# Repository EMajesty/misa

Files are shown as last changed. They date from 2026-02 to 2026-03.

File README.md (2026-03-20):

<p align="center">
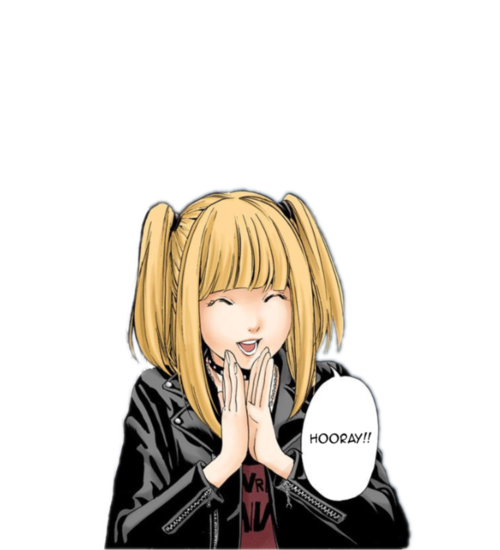
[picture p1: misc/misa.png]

</p>
<h1 align="center">MISA</h1>

<p align="center">
68k SBC somewhat inspired by the Lisa and the Mac, and similar projects around the net.
</p>

<p align="center">
MC68HC000P16 (at 4/8/16 MHz)
<br />
1MB ROM (2x SST39SF040)
<br />
1MB SRAM (2x AS6C4008-55PCN)
<br />
ATF1508 CPLD for glue
<br />
UART
<br />
CF card
<br />
Monochrome display
<br />
Audio with YM2151?
<br />
Keyboard?
<br />
Wifi with WizFi360???
</p>

<p align="center">
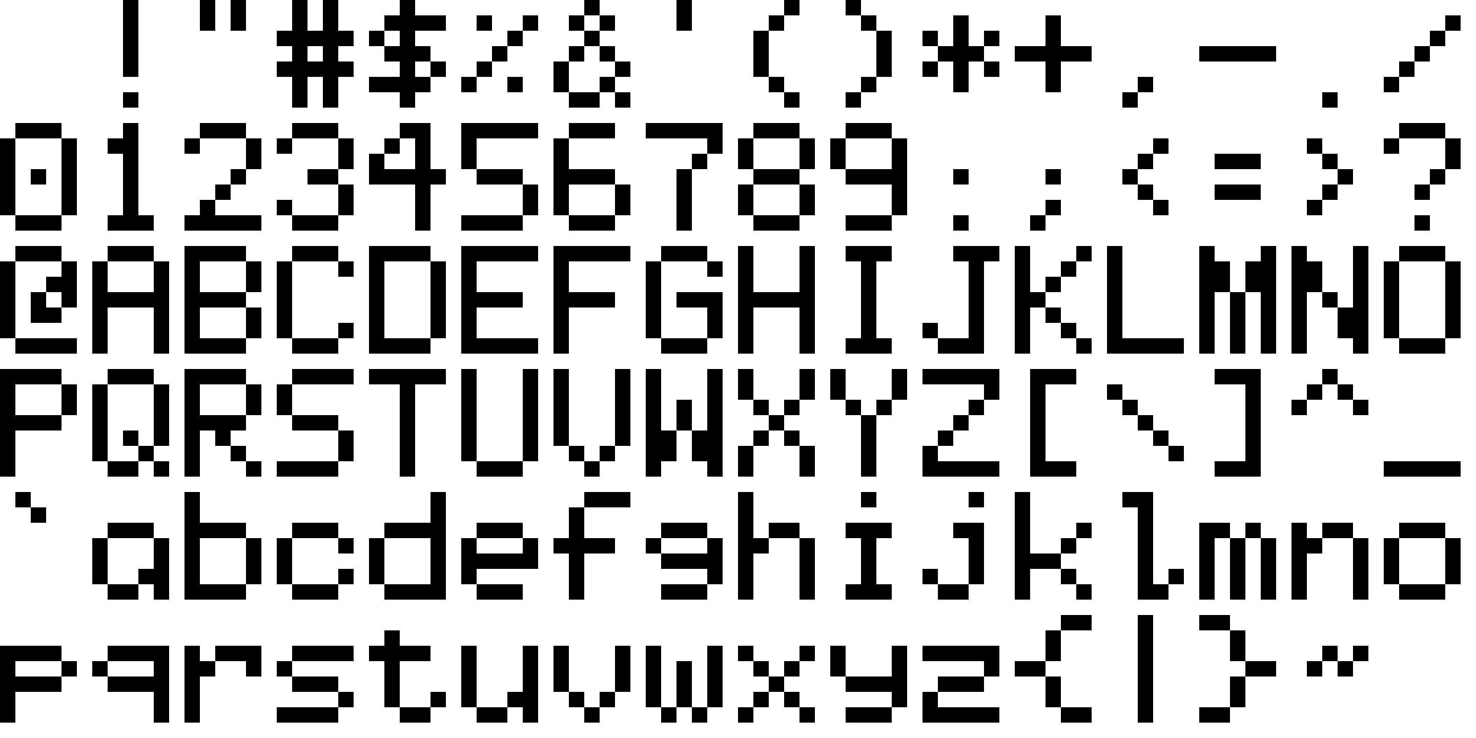
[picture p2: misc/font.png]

</p>

<p align="center">
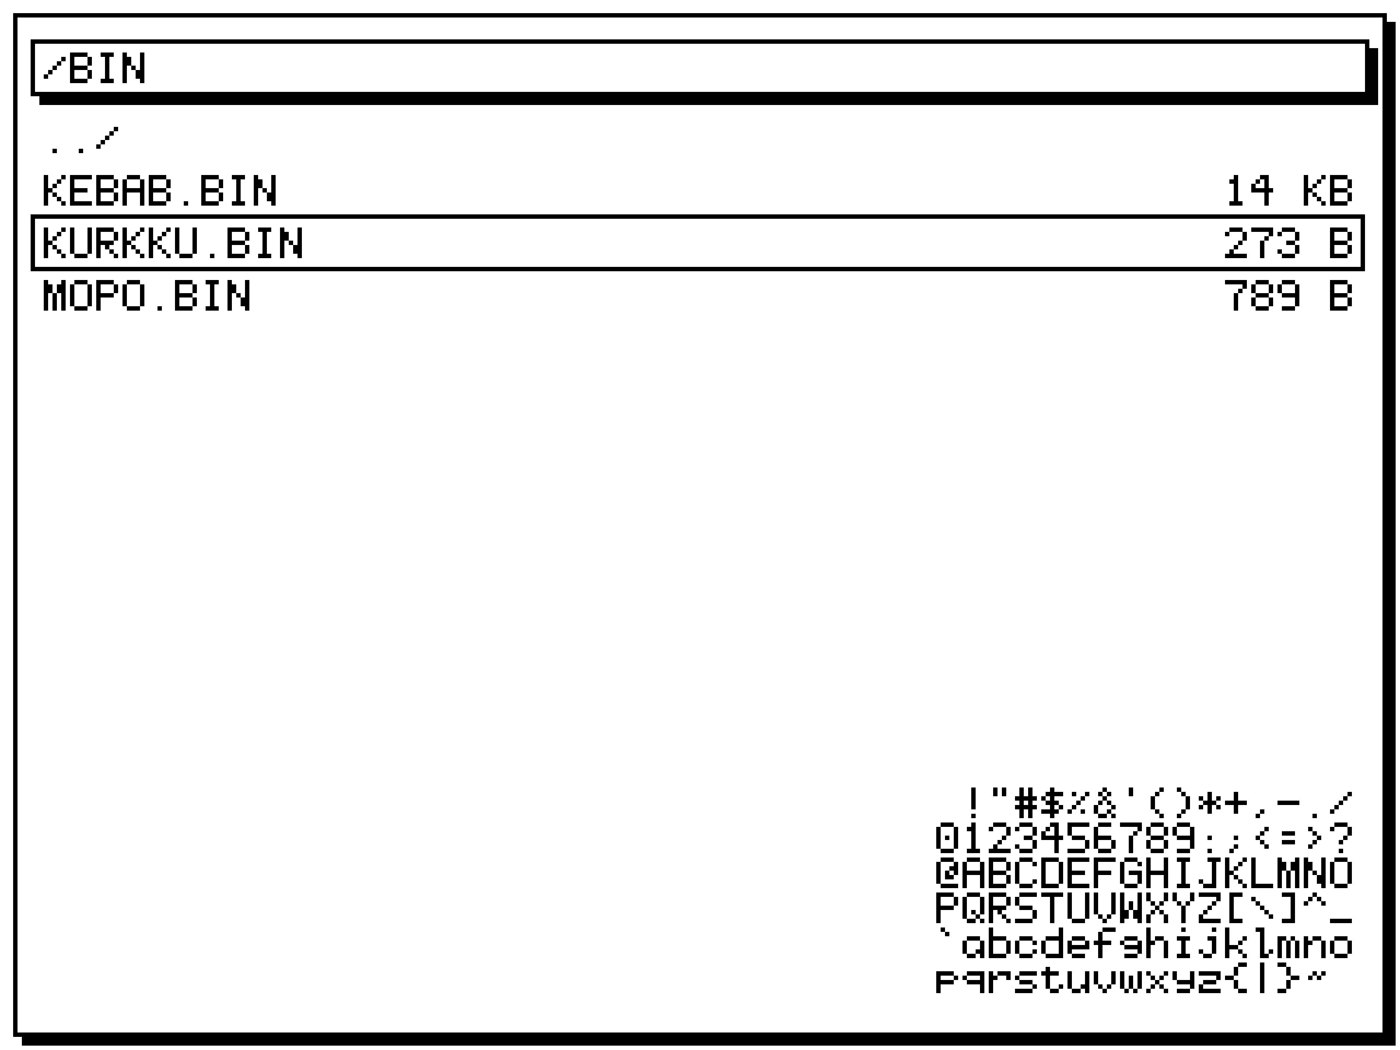
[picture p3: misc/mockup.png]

</p>

### TODO

- [ ] HW proto
- [ ] PLD logic
- [ ] Monitor program
- [ ] UART stuff
- [ ] Display stuff
- [x] Font 
- [ ] Input stuff
- [ ] FAT16/VFAT 
- [ ] File manager
- [ ] A beep
- [ ] Text editor
- [ ] Terminal emulator
- [ ] Lisp interpreter
- [ ] Doom
- [ ] ?????
- [ ] Multitasking kernel

### Docs

[68000 Hardware Manual](https://bitsavers.org/pdf/peripheralTechnology/68000_Hardware_Manual.pdf)

[M68000 User's Manual](https://www.nxp.com/docs/en/reference-manual/MC68000UM.pdf)

### BOM

| Ref | Part | Qty | Package | Datasheet | Notes |
|---|---|---|---|---|---|
||MC68HC000|1|DIP64/PLCC68|[Datasheet](https://igspgm.com/repairs/MC68HC000.pdf)|MPU|
||YM2151|1|DIP24|[Datasheet](https://retrocdn.net/images/1/1c/YM2151_datasheet.pdf)<br/>[Application manual](https://retrocdn.net/images/9/9c/YM2151_Application_Manual.pdf)|Sound|
||YM3012|1|DIP16|[Datasheet](https://datasheet4u.com/pdf-down/Y/M/3/YM3012-Yamaha.pdf)|DAC|
||TDA2822M|1|DIP8|[Datasheet](https://www.mouser.com/catalog/specsheets/stmicroelectronics_cd00000134.pdf)|Power amp|
||AS6C4008-55PCN|2|DIP32|[Datasheet](https://eu.mouser.com/datasheet/3/893/1/AS6C4008.pdf)|SRAM|
||SST39SF040|2|PLCC32|[Datasheet](https://ww1.microchip.com/downloads/aemDocuments/documents/MPD/ProductDocuments/DataSheets/SST39SF010A-SST39SF020A-SST39SF040-Data-Sheet-DS20005022.pdf)|ROM|
||ATF1508AS|1|PLCC84|[Datasheet](https://ww1.microchip.com/downloads/en/DeviceDoc/doc0784.pdf)|CPLD|
||MC68681FN|1|PLCC44|[Datasheet](https://www.microelectronicash.com/downloads/MC68681P.pdf)<br/>[AN-0899](https://www.bitsavers.org/components/motorola/_appNotes/AN-0899_A_Terminal_Interface,_Printer...for_an_MC68000-Based_System_using_the_MC68681_DUART.pdf)|DUART|
||NE555P|1|DIP8|[Datasheet](https://www.ti.com/lit/ds/symlink/se555.pdf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)||
||SN74HC05N|1|DIP14|[Datasheet](https://www.ti.com/lit/ds/symlink/sn74hc05.pdf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)||
||SN74HCT74N|1|DIP14|[Datasheet](https://www.ti.com/lit/ds/symlink/sn74hct74.pdf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)||
||16 MHz oscillator|1|DIP8|[Datasheet](https://www.ctscorp.com/Files/DataSheets/Passives/FCP/Clock-Oscillators/clock-ocillators-MXO45_MXO45HS-datasheet.pdf)||
||3.6864 MHz oscillator|1|DIP8|[Datasheet](https://www.ctscorp.com/Files/DataSheets/Passives/FCP/Clock-Oscillators/clock-ocillators-MXO45_MXO45HS-datasheet.pdf)||
||WizFi360-CON|1||[Datasheet](https://docs.wiznet.io/pdf-viewer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)|WIFI|
||5.7" 320240 RA8835|1||[Module](https://www.buydisplay.com/download/manual/ERM320240-1_Series_Datasheet.pdf)<br />[Controller](https://www.buydisplay.com/download/ic/RA8835.pdf)|Display|

### Memory map (RAM vectors + 2 MiB I/O)

| Region | Start | End | Size | Notes |
|---|---|---|---|---|
| ROM | 0x00000000 | 0x000FFFFF | 1 MiB  | 2x SST39SF040; contains reset vectors, monitor, bootloader; early startup runs from here. |
| Vectors | 0x00100000 | 0x001003FF | 1 KiB  | Vector table copied from ROM into RAM at boot; CPU configured to use RAM vectors.|
| RAM | 0x00100000 | 0x001FFFFF | 1 MiB  | Same 1 MiB SRAM; low area holds vectors + kernel data, high end used for supervisor/user stacks and heap. |
| I/O | 0x00E00000 | 0x00FFFFFF | 2 MiB  | CPLD‑decoded I/O window for UART, IDE/CF, keyboard, video, audio, WiFi, unused space.|
| Unused  | Everything else | - | - ||

### I/O submap (0x00E00000–0x00FFFFFF)

| Device | CS | Start | End | Size | Bus width | Notes |
|---|---|---|---|---|---|---|
| UART | UART_CS | 0x00E00000 | 0x00E00FFF | 4 KiB | 8‑bit | MC68681FN on D0–D7, RS0–RS3 from CPU A1–A4.|
| IDE / CF| IDE_CS0/1 | 0x00E01000 | 0x00E01FFF | 4 KiB | 16‑bit | 16‑bit data path via CPLD, command/control regs.|
| Keyboard| KBD_CS | 0x00E02000 | 0x00E02FFF | 4 KiB | 8‑bit | Simple DATA/STATUS/CONTROL registers.|
| Video | VID_CS | 0x00E03000 | 0x00E03FFF | 4 KiB | 8‑ or 16‑bit | RA8835 controller regs; framebuffer mapped elsewhere or via paging.|
| Audio | AUD_CS | 0x00E04000 | 0x00E04FFF | 4 KiB | 8‑bit | YM2151 register interface; DAC/analog path is fixed hardware, no CPU control.|
| WiFi | WIFI_CS | 0x00E05000 | 0x00E05FFF | 4 KiB | 8‑bit | WizFi360 memory‑mapped UART/command regs (future). |
| Unused  | – | 0x00E06000 | 0x00FFFFFF | ~1.97 MiB | 8‑ or 16‑bit ||

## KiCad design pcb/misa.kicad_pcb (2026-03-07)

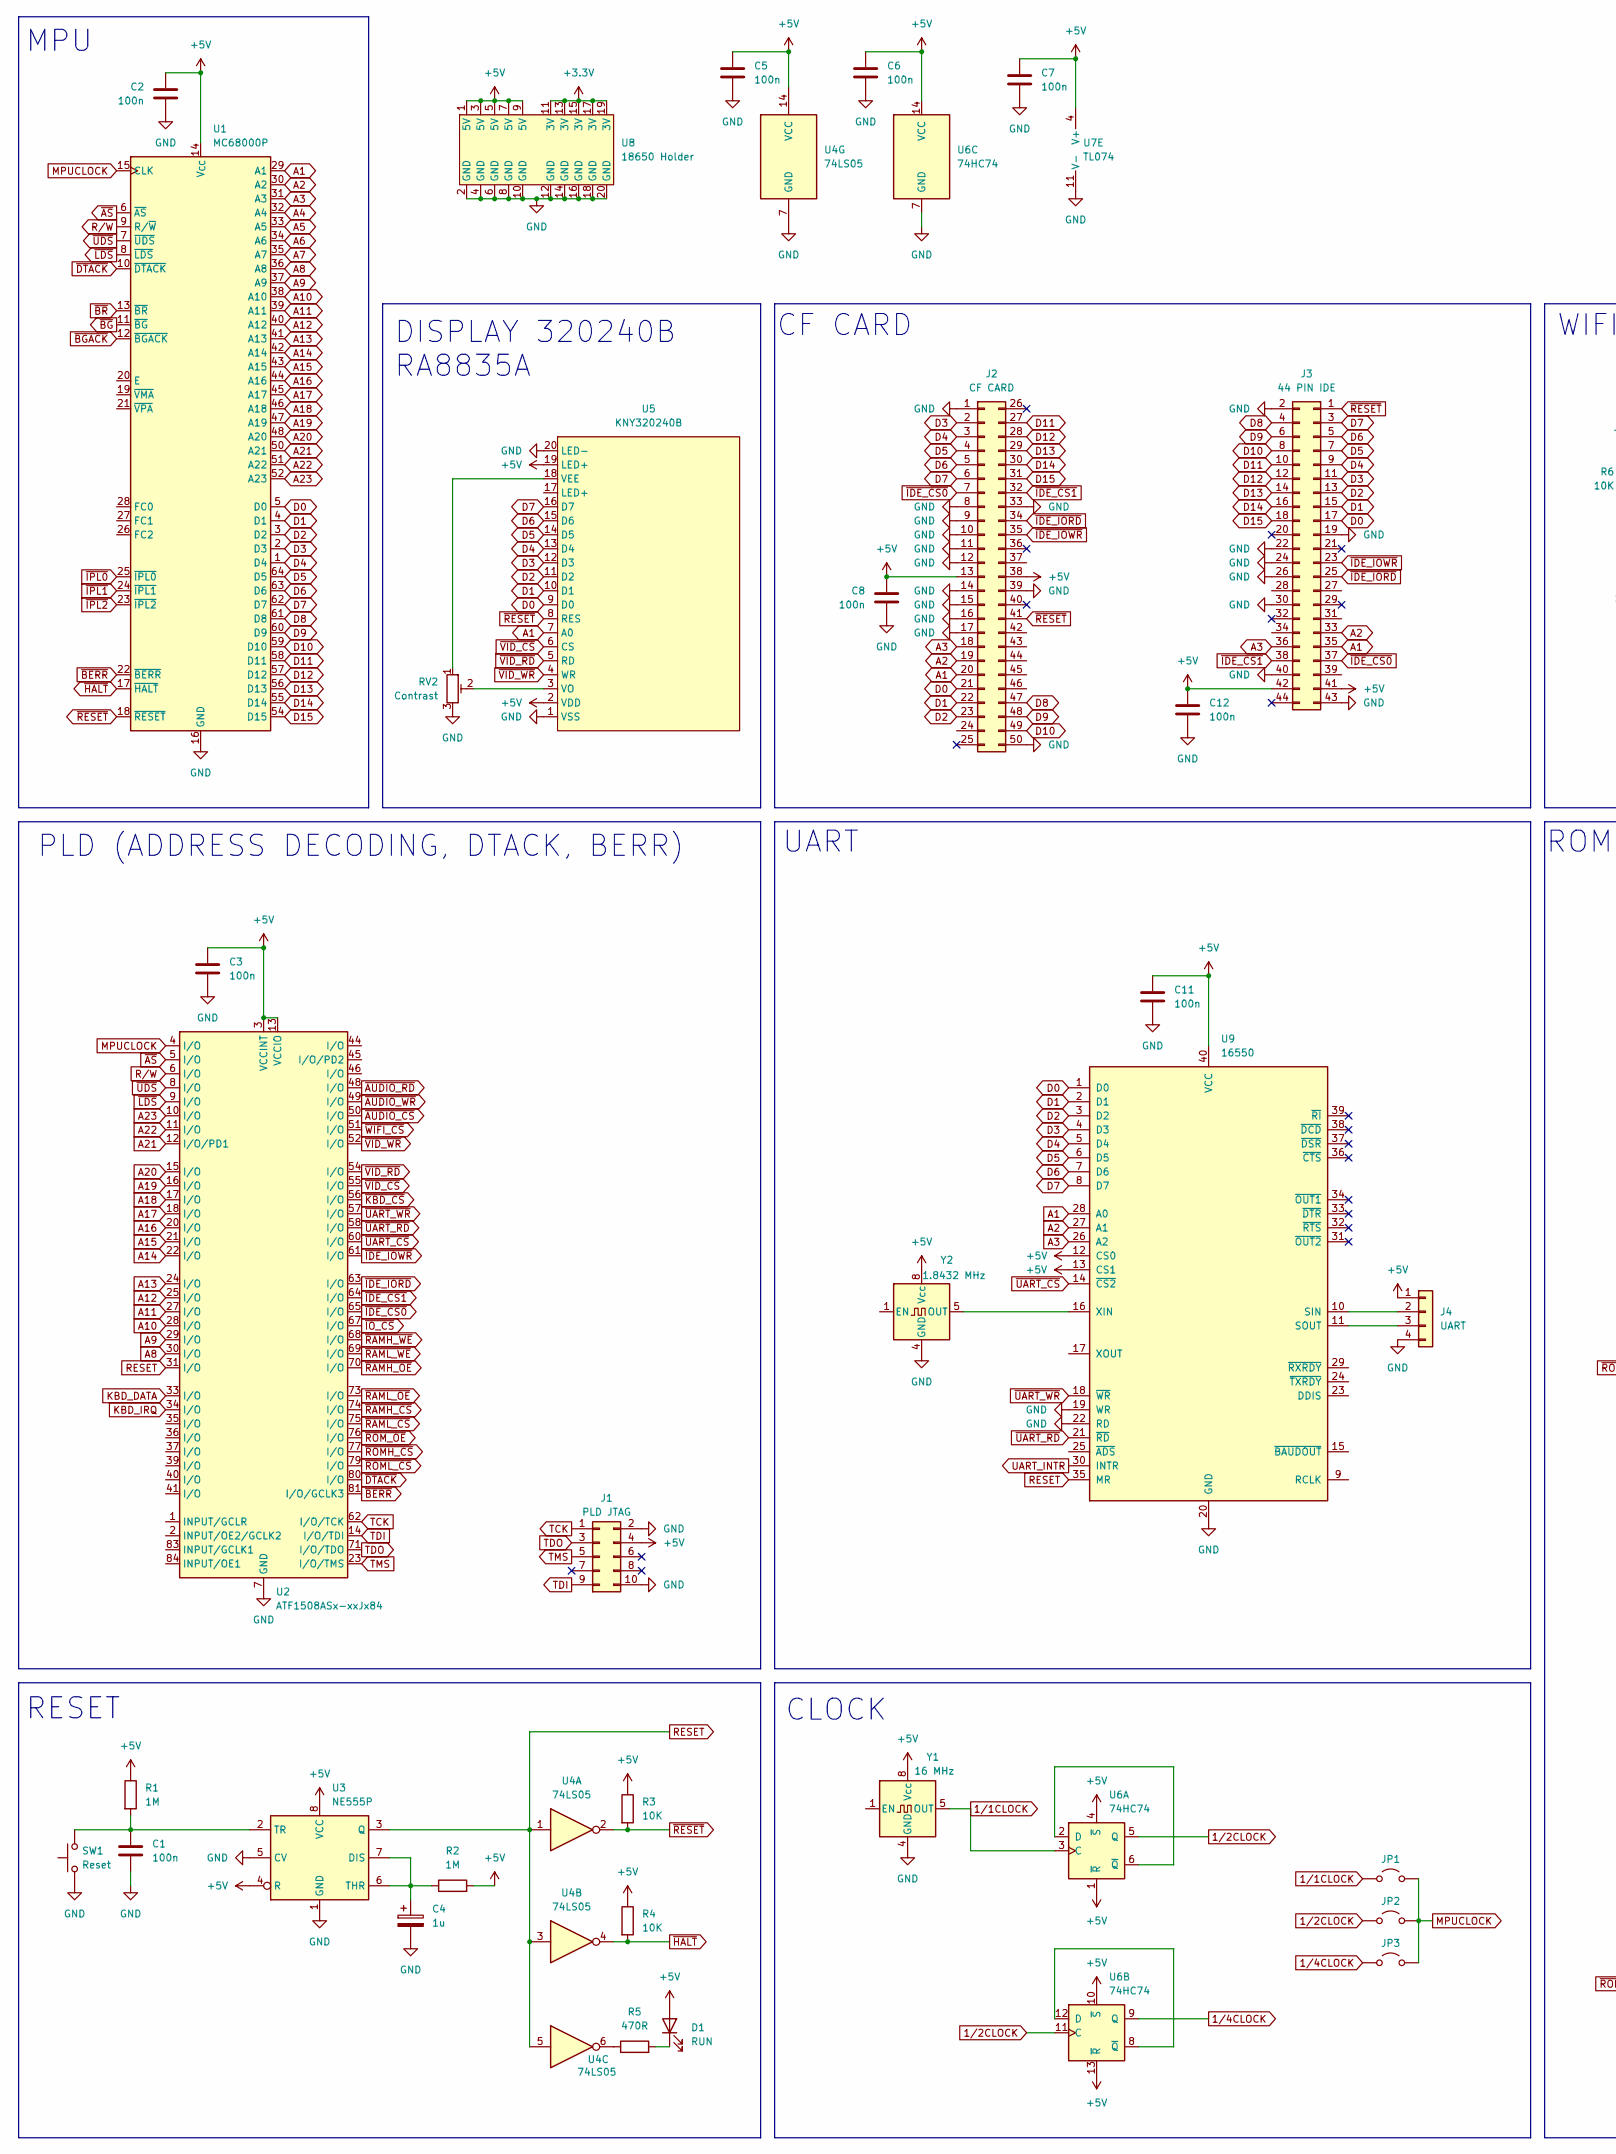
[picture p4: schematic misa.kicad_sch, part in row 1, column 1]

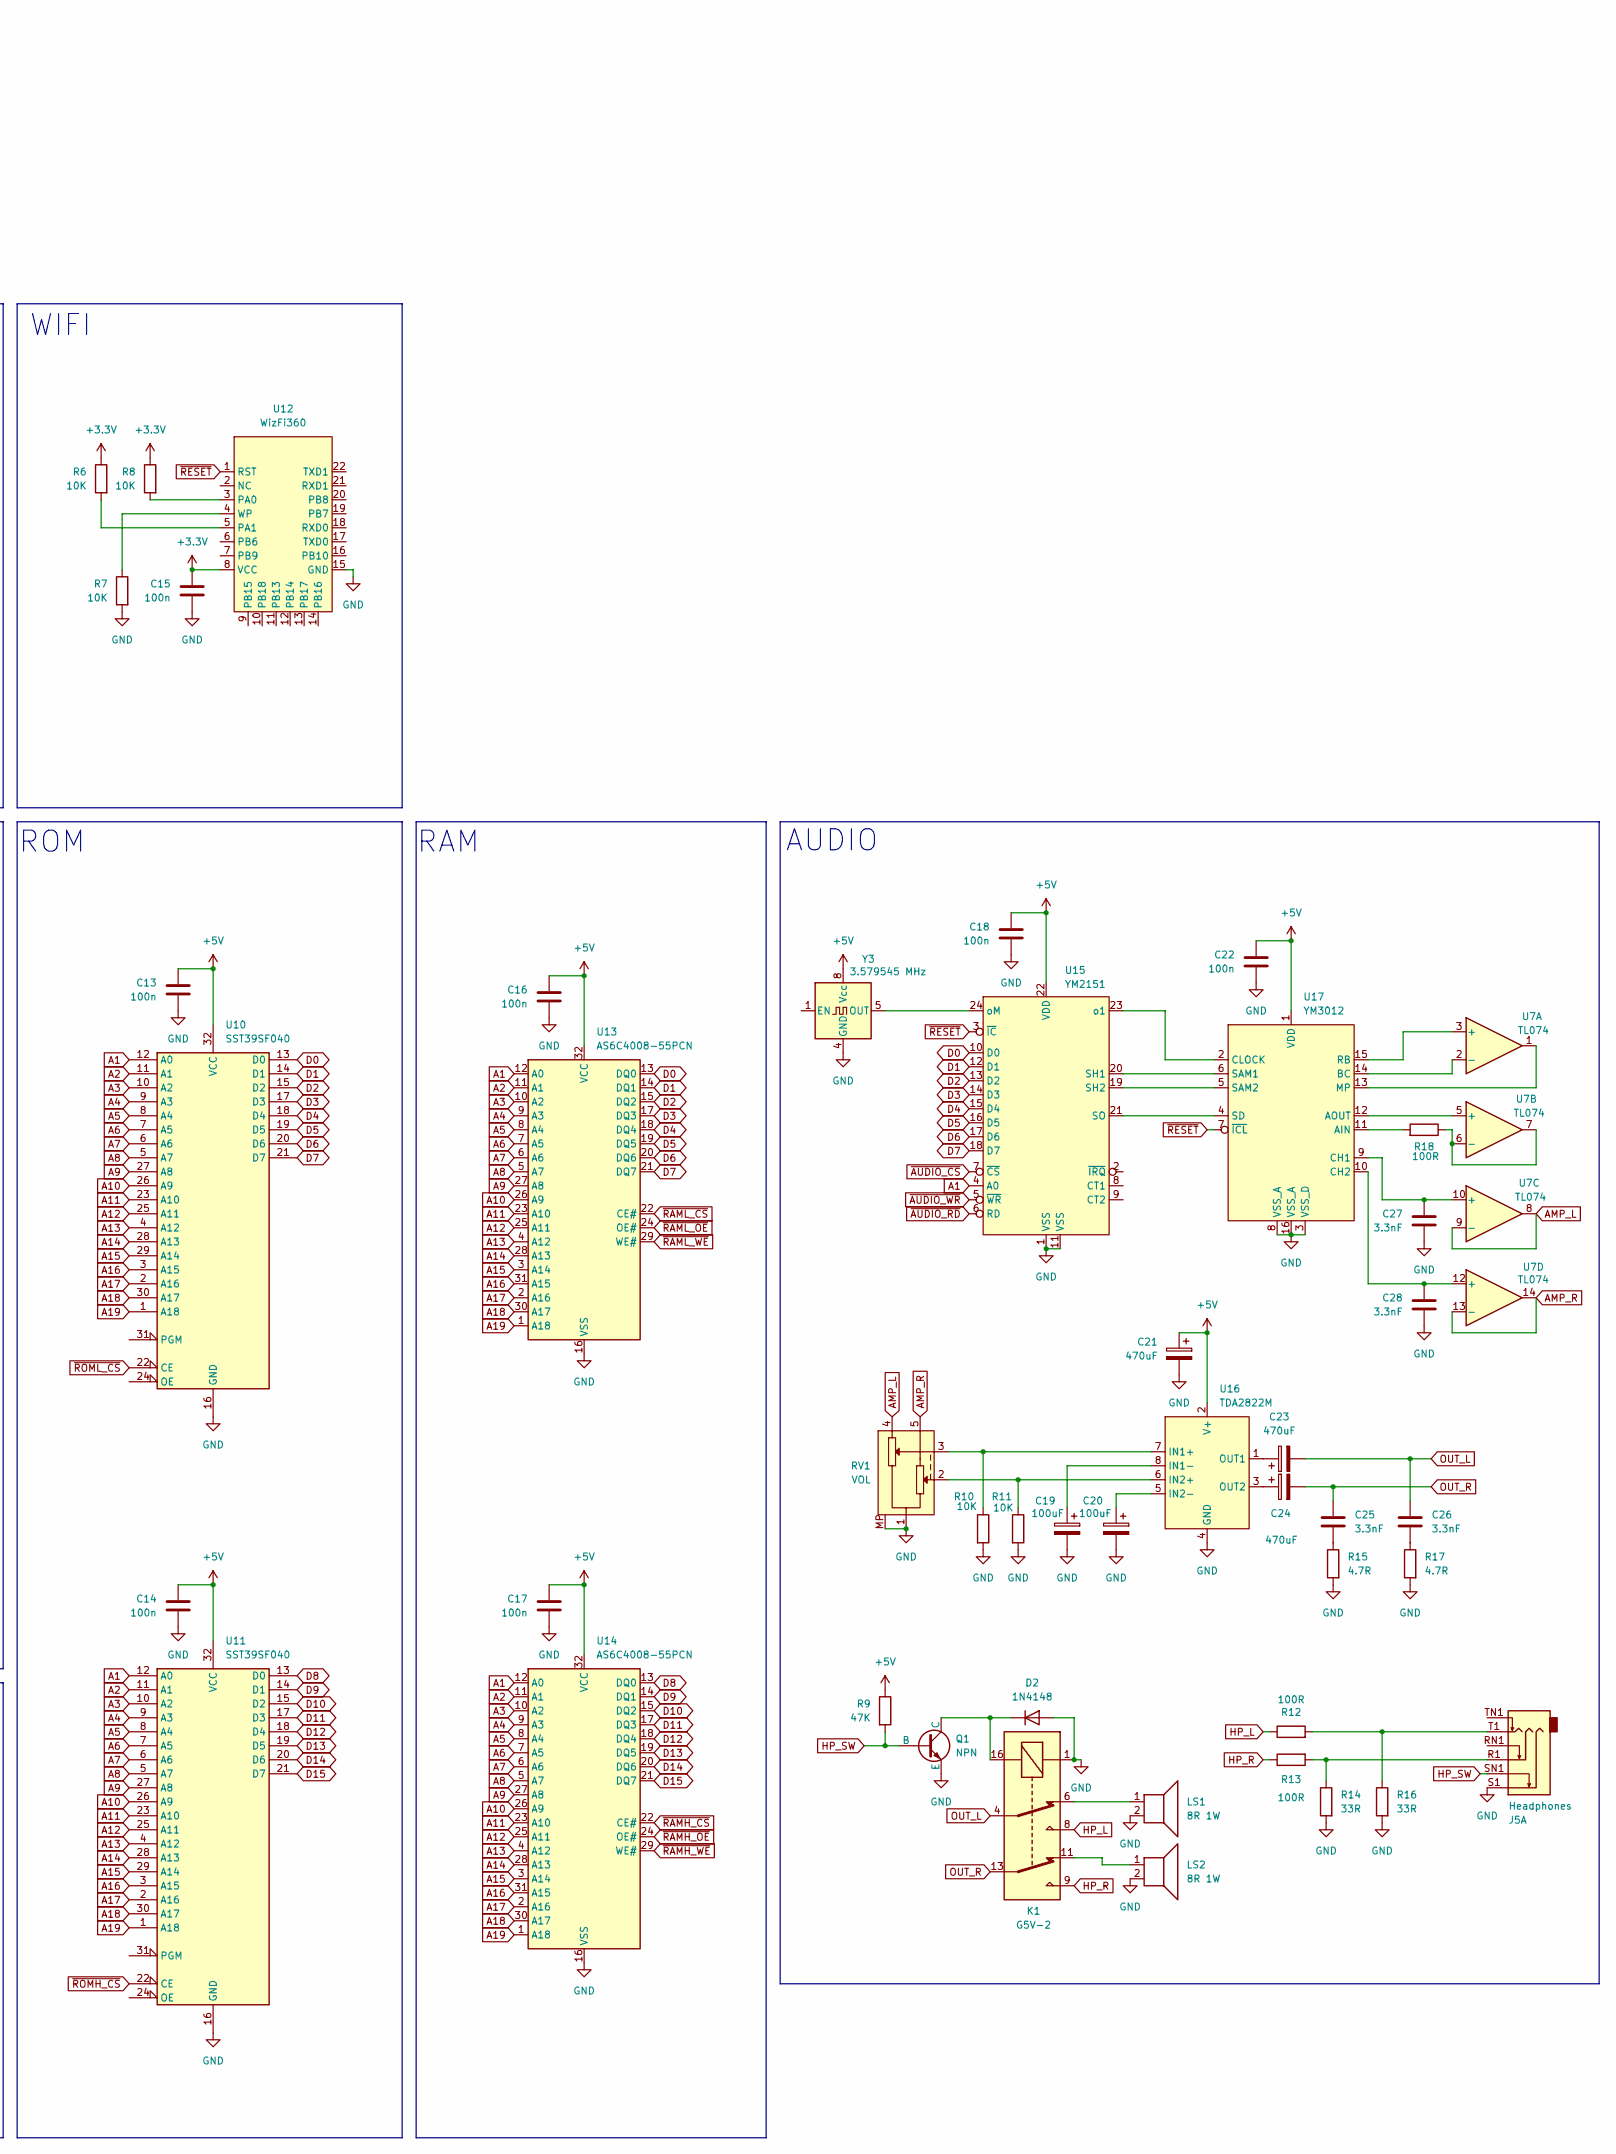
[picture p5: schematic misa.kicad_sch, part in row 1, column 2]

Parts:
C1, C2, C3, C5, C6, C7, C8, C11, C12, C13, C14, C15, C16, C17, C18, C22: 100n; C_Rect_L7.0mm_W2.5mm_P5.00mm
C4: 1u; CP_Radial_D4.0mm_P2.00mm
C19, C20: 100uF; CP_Radial_D5.0mm_P2.50mm
C21, C23, C24: 470uF; CP_Radial_D6.3mm_P2.50mm
C25, C26, C27, C28: 3.3nF; C_Rect_L7.0mm_W2.5mm_P5.00mm
D1: RUN; LED_D3.0mm
D2: 1N4148; D_DO-35_SOD27_P7.62mm_Horizontal
J1: PLD JTAG; Pins_2x05_2.54mm_TH; Part Number 1-1002FBV0T
J2: CF CARD; CF_Card_Socket_PTH
J3: 44 PIN IDE; PinSocket_2x22_P2.54mm_Vertical
J4: UART; Pins_1x04_2.54mm_TH_SWD; Part Number 1-0401FBV0T
J5: Headphones; Jack_6.35mm_Neutrik_NMJ6HFD2-AU_Horizontal
JP1, JP2, JP3: Jumper_2_Open; PinHeader_1x02_P2.54mm_Vertical
K1: G5V-2; Relay_DPDT_Omron_G5V-2
LS1, LS2: 8R 1W; PinHeader_1x02_P2.54mm_Vertical
Q1: NPN; TO-92L_Inline_Wide
R1, R2: 1M; R_Axial_DIN0207_L6.3mm_D2.5mm_P7.62mm_Horizontal
R3, R4, R6, R7, R8, R10, R11: 10K; R_Axial_DIN0207_L6.3mm_D2.5mm_P7.62mm_Horizontal
R5: 470R; R_Axial_DIN0207_L6.3mm_D2.5mm_P7.62mm_Horizontal
R9: 47K; R_Axial_DIN0207_L6.3mm_D2.5mm_P7.62mm_Horizontal
R12, R13, R18: 100R; R_Axial_DIN0207_L6.3mm_D2.5mm_P7.62mm_Horizontal
R14, R16: 33R; R_Axial_DIN0207_L6.3mm_D2.5mm_P7.62mm_Horizontal
R15, R17: 4.7R; R_Axial_DIN0207_L6.3mm_D2.5mm_P7.62mm_Horizontal
RV1: VOL
RV2: Contrast
SW1: Reset
U1: MC68000P; PLCC-68_THT-Socket
U2: ATF1508ASx-xxJx84; PLCC-84_THT-Socket
U3: NE555P; DIP-8_W7.62mm
U4: 74LS05; DIP-14_W7.62mm_Socket_LongPads
U5: KNY320240B
U6: 74HC74; DIP-14_W7.62mm_Socket_LongPads
U7: TL074; DIP-14_W7.62mm_Socket_LongPads
U8: 18650 Holder; 18650_holder
U9: 16550; PLCC-44_THT-Socket
U10, U11: SST39SF040; PLCC-32_THT-Socket
U12: WizFi360; Untitled
U13, U14: AS6C4008-55PCN; DIP-32_W15.24mm
U15: YM2151; DIP-24_18.0mmx34.29mm_W15.24mm_Socket_LongPads
U16: TDA2822M; DIP-8_W7.62mm_Socket_LongPads
U17: YM3012; DIP-16_W7.62mm_Socket_LongPads
Y1: 16 MHz; Oscillator_DIP-8
Y2: 1.8432 MHz; Oscillator_DIP-8
Y3: 3.579545 MHz; Oscillator_DIP-8

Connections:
1/1CLOCK: JP1.1 (A), U6.3 (C), Y1.5 (OUT)
1/2CLOCK: JP2.1 (A), U6.5 (Q), U6.11 (C)
1/4CLOCK: JP3.1 (A), U6.9 (Q)
+3.3V: C15.1, R6.1, R8.1, U8.11 (3V), U8.13 (3V), U8.15 (3V), U8.17 (3V), U8.19 (3V), U12.8 (VCC)
+5V: C2.1, C3.1, C5.1, C6.1, C7.1, C8.1, C11.1, C12.1, C13.1, C14.1, C16.1, C17.1, C18.1, C21.1, C22.1, D1.2 (A), J1.4 (GND), J2.13, J2.38, J3.41, J3.42, J4.1, R1.1, R2.2, R3.1, R4.1, R9.1, U1.14 (V_{CC}), U1.49 (V_{CC}), U2.3 (VCCINT), U2.13 (VCCIO), U2.26 (VCCIO), U2.38 (VCCIO), U2.43 (VCCINT), U2.53 (VCCIO), U2.66 (VCCIO), U2.78 (VCCIO), U3.4 (R), U3.8 (VCC), U4.14 (VCC), U5.2 (VDD), U5.19 (LED+), U6.1 (~R), U6.4 (~S), U6.10 (~S), U6.13 (~R), U6.14 (VCC), U7.4 (V+), U8.1 (5V), U8.3 (5V), U8.5 (5V), U8.7 (5V), U8.9 (5V), U9.12 (CS0), U9.13 (CS1), U9.40 (VCC), U10.32 (VCC), U11.32 (VCC), U13.32 (VCC), U14.32 (VCC), U15.22 (VDD), U16.2 (V+), U17.1 (VDD), Y1.8 (Vcc), Y2.8 (Vcc), Y3.8 (Vcc)
A1: J2.20, J3.35, U1.29 (A1), U5.7 (A0), U9.28 (A0), U10.12 (A0), U11.12 (A0), U13.12 (A0), U14.12 (A0), U15.4 (A0)
A2: J2.19, J3.33, U1.30 (A2), U9.27 (A1), U10.11 (A1), U11.11 (A1), U13.11 (A1), U14.11 (A1)
A3: J2.18, J3.36, U1.31 (A3), U9.26 (A2), U10.10 (A2), U11.10 (A2), U13.10 (A2), U14.10 (A2)
A4: U1.32 (A4), U10.9 (A3), U11.9 (A3), U13.9 (A3), U14.9 (A3)
A5: U1.33 (A5), U10.8 (A4), U11.8 (A4), U13.8 (A4), U14.8 (A4)
A6: U1.34 (A6), U10.7 (A5), U11.7 (A5), U13.7 (A5), U14.7 (A5)
A7: U1.35 (A7), U10.6 (A6), U11.6 (A6), U13.6 (A6), U14.6 (A6)
A8: U1.36 (A8), U2.30 (I/O), U10.5 (A7), U11.5 (A7), U13.5 (A7), U14.5 (A7)
A9: U1.37 (A9), U2.29 (I/O), U10.27 (A8), U11.27 (A8), U13.27 (A8), U14.27 (A8)
A10: U1.38 (A10), U2.28 (I/O), U10.26 (A9), U11.26 (A9), U13.26 (A9), U14.26 (A9)
A11: U1.39 (A11), U2.27 (I/O), U10.23 (A10), U11.23 (A10), U13.23 (A10), U14.23 (A10)
A12: U1.40 (A12), U2.25 (I/O), U10.25 (A11), U11.25 (A11), U13.25 (A11), U14.25 (A11)
A13: U1.41 (A13), U2.24 (I/O), U10.4 (A12), U11.4 (A12), U13.4 (A12), U14.4 (A12)
A14: U1.42 (A14), U2.22 (I/O), U10.28 (A13), U11.28 (A13), U13.28 (A13), U14.28 (A13)
A15: U1.43 (A15), U2.21 (I/O), U10.29 (A14), U11.29 (A14), U13.3 (A14), U14.3 (A14)
A16: U1.44 (A16), U2.20 (I/O), U10.3 (A15), U11.3 (A15), U13.31 (A15), U14.31 (A15)
A17: U1.45 (A17), U2.18 (I/O), U10.2 (A16), U11.2 (A16), U13.2 (A16), U14.2 (A16)
A18: U1.46 (A18), U2.17 (I/O), U10.30 (A17), U11.30 (A17), U13.30 (A17), U14.30 (A17)
A19: U1.47 (A19), U2.16 (I/O), U10.1 (A18), U11.1 (A18), U13.1 (A18), U14.1 (A18)
A20: U1.48 (A20), U2.15 (I/O)
A21: U1.50 (A21), U2.12 (I/O/PD1)
A22: U1.51 (A22), U2.11 (I/O)
A23: U1.52 (A23), U2.10 (I/O)
AMP_L: RV1.4, U7.8, U7.9 (-)
AMP_R: RV1.5, U7.13 (-), U7.14
D0: J2.21, J3.17, U1.5 (D0), U5.9 (D0), U9.1 (D0), U10.13 (D0), U13.13 (DQ0), U15.10 (D0)
D1: J2.22, J3.15, U1.4 (D1), U5.10 (D1), U9.2 (D1), U10.14 (D1), U13.14 (DQ1), U15.12 (D1)
D2: J2.23, J3.13, U1.3 (D2), U5.11 (D2), U9.3 (D2), U10.15 (D2), U13.15 (DQ2), U15.13 (D2)
D3: J2.2, J3.11, U1.2 (D3), U5.12 (D3), U9.4 (D3), U10.17 (D3), U13.17 (DQ3), U15.14 (D3)
D4: J2.3, J3.9, U1.1 (D4), U5.13 (D4), U9.5 (D4), U10.18 (D4), U13.18 (DQ4), U15.15 (D4)
D5: J2.4, J3.7, U1.64 (D5), U5.14 (D5), U9.6 (D5), U10.19 (D5), U13.19 (DQ5), U15.16 (D5)
D6: J2.5, J3.5, U1.63 (D6), U5.15 (D6), U9.7 (D6), U10.20 (D6), U13.20 (DQ6), U15.17 (D6)
D7: J2.6, J3.3, U1.62 (D7), U5.16 (D7), U9.8 (D7), U10.21 (D7), U13.21 (DQ7), U15.18 (D7)
D8: J2.47, J3.4, U1.61 (D8), U11.13 (D0), U14.13 (DQ0)
D9: J2.48, J3.6, U1.60 (D9), U11.14 (D1), U14.14 (DQ1)
D10: J2.49, J3.8, U1.59 (D10), U11.15 (D2), U14.15 (DQ2)
D11: J2.27, J3.10, U1.58 (D11), U11.17 (D3), U14.17 (DQ3)
D12: J2.28, J3.12, U1.57 (D12), U11.18 (D4), U14.18 (DQ4)
D13: J2.29, J3.14, U1.56 (D13), U11.19 (D5), U14.19 (DQ5)
D14: J2.30, J3.16, U1.55 (D14), U11.20 (D6), U14.20 (DQ6)
D15: J2.31, J3.18, U1.54 (D15), U11.21 (D7), U14.21 (DQ7)
GND: C1.2, C2.2, C3.2, C4.2, C5.2, C6.2, C7.2, C8.2, C11.2, C12.2, C13.2, C14.2, C15.2, C16.2, C17.2, C18.2, C19.2, C20.2, C21.2, C22.2, C27.2, C28.2, D2.2 (A), J1.2 (+12V), J1.10 (-12V), J2.1, J2.8, J2.9, J2.10, J2.11, J2.12, J2.14, J2.15, J2.16, J2.17, J2.33, J2.39, J2.50, J3.2, J3.19, J3.22, J3.24, J3.26, J3.30, J3.40, J3.43, J4.4, J5.S1, K1.1, LS1.2, LS2.2, Q1.3 (E), R7.2, R10.2, R11.2, R14.2, R15.2, R16.2, R17.2, RV1.1, RV1.MP, RV2.3, SW1.1, U1.16 (GND), U1.53 (GND), U2.7 (GND), U2.19 (GND), U2.32 (GND), U2.42 (GND), U2.47 (GND), U2.59 (GND), U2.72 (GND), U2.82 (GND), U3.1 (GND), U3.5 (CV), U4.7 (GND), U5.1 (VSS), U5.20 (LED-), U6.7 (GND), U7.11 (V-), U8.2 (GND), U8.4 (GND), U8.6 (GND), U8.8 (GND), U8.10 (GND), U8.12 (GND), U8.14 (GND), U8.16 (GND), U8.18 (GND), U8.20 (GND), U9.19 (WR), U9.20 (GND), U9.22 (RD), U10.16 (GND), U11.16 (GND), U12.15 (GND), U13.16 (VSS), U14.16 (VSS), U15.1 (VSS), U15.11 (VSS), U16.4 (GND), U17.3 (VSS_D), U17.8 (VSS_A), U17.16 (VSS_A), Y1.4 (GND), Y2.4 (GND), Y3.4 (GND)
HP_L: K1.8, R12.1
HP_R: K1.9, R13.1
HP_SW: J5.SN1, Q1.2 (B), R9.2
KBD_DATA: U2.33 (I/O)
KBD_IRQ: U2.34 (I/O)
MPUCLOCK: JP1.2 (B), JP2.2 (B), JP3.2 (B), U1.15 (CLK), U2.4 (I/O)
unnamed: C25.2, R15.1
unnamed: C26.2, R17.1
unnamed: D1.1 (K), R5.2
unnamed: D2.1 (K), K1.16, Q1.1 (C)
unnamed: J4.2, U9.10 (SIN)
unnamed: J4.3, U9.11 (SOUT)
unnamed: J5.R1, R13.2, R14.1
unnamed: J5.T1, R12.2, R16.1
unnamed: K1.6, LS1.1
unnamed: K1.11, LS2.1
unnamed: R5.1, U4.6
unnamed: RV2.1, U5.18 (VEE)
unnamed: RV2.2, U5.3 (VO)
unnamed: C4.1, R2.1, U3.6 (THR), U3.7 (DIS)
unnamed: C1.1, R1.2, SW1.2, U3.2 (TR)
unnamed: U6.2 (D), U6.6 (~Q)
unnamed: U6.8 (~Q), U6.12 (D)
unnamed: R18.1, U7.6 (-), U7.7
unnamed: U9.16 (XIN), Y2.5 (OUT)
unnamed: R8.2, U12.3 (PA0)
unnamed: R6.2, U12.5 (PA1)
unnamed: R7.1, U12.4 (WP)
unnamed: U15.20 (SH1), U17.6 (SAM1)
unnamed: U15.19 (SH2), U17.5 (SAM2)
unnamed: U15.21 (SO), U17.4 (SD)
unnamed: U15.23 (o1), U17.2 (CLOCK)
unnamed: U15.24 (oM), Y3.5 (OUT)
unnamed: R10.1, RV1.3, U16.7 (IN1+)
unnamed: C19.1, U16.8 (IN1-)
unnamed: R11.1, RV1.2, U16.6 (IN2+)
unnamed: C20.1, U16.5 (IN2-)
unnamed: C23.1, U16.1 (OUT1)
unnamed: C24.1, U16.3 (OUT2)
unnamed: R18.2, U17.11 (AIN)
unnamed: U7.5 (+), U17.12 (AOUT)
unnamed: U7.2 (-), U17.14 (BC)
unnamed: C27.1, U7.10 (+), U17.9 (CH1)
unnamed: C28.1, U7.12 (+), U17.10 (CH2)
unnamed: U7.1, U17.13 (MP)
unnamed: U7.3 (+), U17.15 (RB)
OUT_L: C23.2, C26.1, K1.4
OUT_R: C24.2, C25.1, K1.13
RESET: U2.31 (I/O), U3.3 (Q), U4.1, U4.3, U4.5, U9.35 (MR)
R/W: U1.9 (R/~W), U2.6 (I/O)
TCK: J1.1 (+12V), U2.62 (I/O/TCK)
TDI: J1.9 (-12V), U2.14 (I/O/TDI)
TDO: J1.3 (GND), U2.71 (I/O/TDO)
TMS: J1.5 (GND), U2.23 (I/O/TMS)
UART_INTR: U9.30 (INTR)
~AS: U1.6 (~AS), U2.5 (I/O)
~AUDIO_CS: U2.50 (I/O), U15.7 (~CS)
~AUDIO_RD: U2.48 (I/O), U15.6 (RD)
~AUDIO_WR: U2.49 (I/O), U15.5 (~WR)
~BERR: U1.22 (~BERR), U2.81 (I/O/GCLK3)
~BGACK: U1.12 (~BGACK)
~BG: U1.11 (~BG)
~BR: U1.13 (~BR)
~DTACK: U1.10 (~DTACK), U2.80 (I/O)
~HALT: R4.2, U1.17 (~HALT), U4.4
~IDE_CS0: J2.7, J3.37, U2.65 (I/O)
~IDE_CS1: J2.32, J3.38, U2.64 (I/O)
~IDE_IORD: J2.34, J3.25, U2.63 (I/O)
~IDE_IOWR: J2.35, J3.23, U2.61 (I/O)
~IO_CS: U2.67 (I/O)
~IPL0: U1.25 (~IPL0)
~IPL1: U1.24 (~IPL1)
~IPL2: U1.23 (~IPL2)
~KBD_CS: U2.56 (I/O)
~LDS: U1.8 (~LDS), U2.9 (I/O)
~RAMH_CS: U2.74 (I/O), U14.22 (CE#)
~RAMH_OE: U2.70 (I/O), U14.24 (OE#)
~RAMH_WE: U2.68 (I/O), U14.29 (WE#)
~RAML_CS: U2.75 (I/O), U13.22 (CE#)
~RAML_OE: U2.73 (I/O), U13.24 (OE#)
~RAML_WE: U2.69 (I/O), U13.29 (WE#)
~RESET: J2.41, J3.1, R3.2, U1.18 (~RESET), U4.2, U5.8 (RES), U12.1 (RST), U15.3 (~IC), U17.7 (~ICL)
~ROMH_CS: U2.77 (I/O), U11.22 (CE)
~ROML_CS: U2.79 (I/O), U10.22 (CE)
~ROM_OE: U2.76 (I/O)
~UART_CS: U2.60 (I/O), U9.14 (~CS2)
~UART_RD: U2.58 (I/O), U9.21 (~RD)
~UART_WR: U2.57 (I/O), U9.18 (~WR)
~UDS: U1.7 (~UDS), U2.8 (I/O)
~VID_CS: U2.55 (I/O), U5.6 (CS)
~VID_RD: U2.54 (I/O), U5.5 (RD)
~VID_WR: U2.52 (I/O), U5.4 (WR)
~WIFI_CS: U2.51 (I/O)

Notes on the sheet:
CF CARD
AUDIO
DISPLAY 320240B RA8835A
RESET
UART
RAM
ROM
MPU
PLD (ADDRESS DECODING, DTACK, BERR)
WIFI
CLOCK

Board: 2 copper layers, 78 parts (2 on the bottom side), 125 nets, no tracks yet.
